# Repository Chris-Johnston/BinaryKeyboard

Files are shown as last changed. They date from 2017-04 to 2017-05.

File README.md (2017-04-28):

# BinaryKeyboard
A two-button backlit mechanical keyboard that types ASCII values, one bit at a time.

## Photos

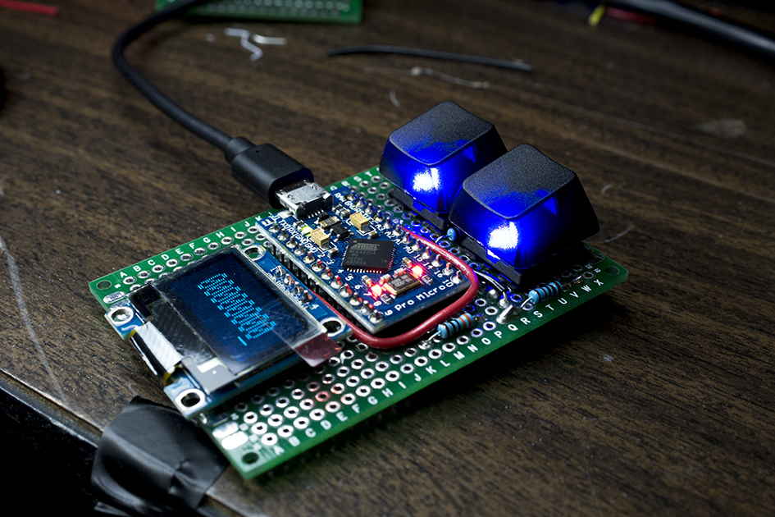
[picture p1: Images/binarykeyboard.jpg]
Photo of Binary Keyboard

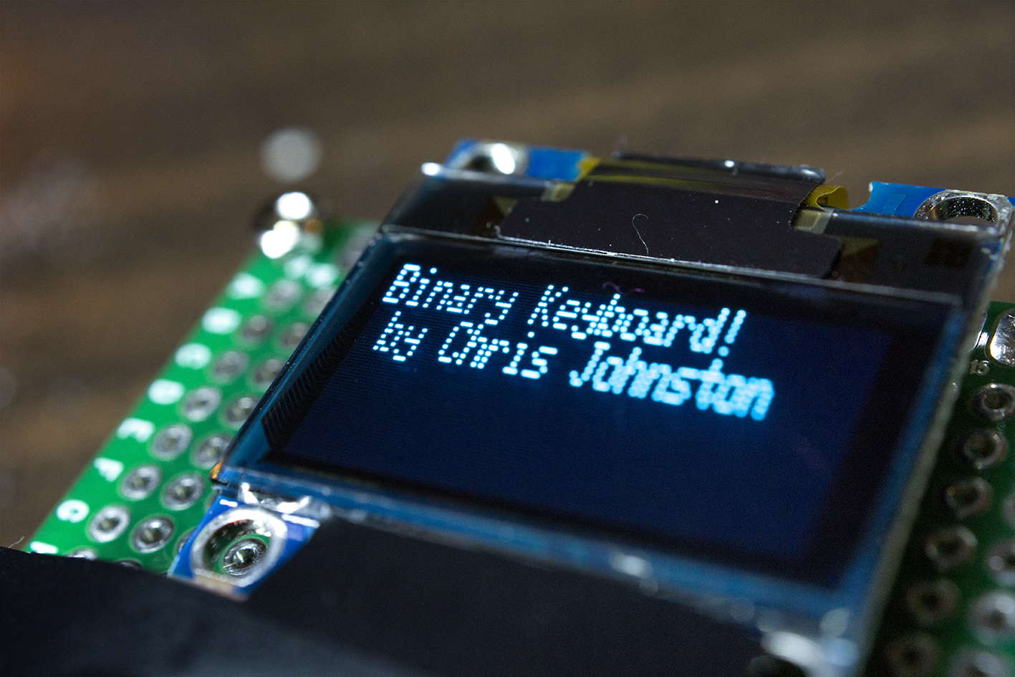
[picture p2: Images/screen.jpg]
Photo of Screen

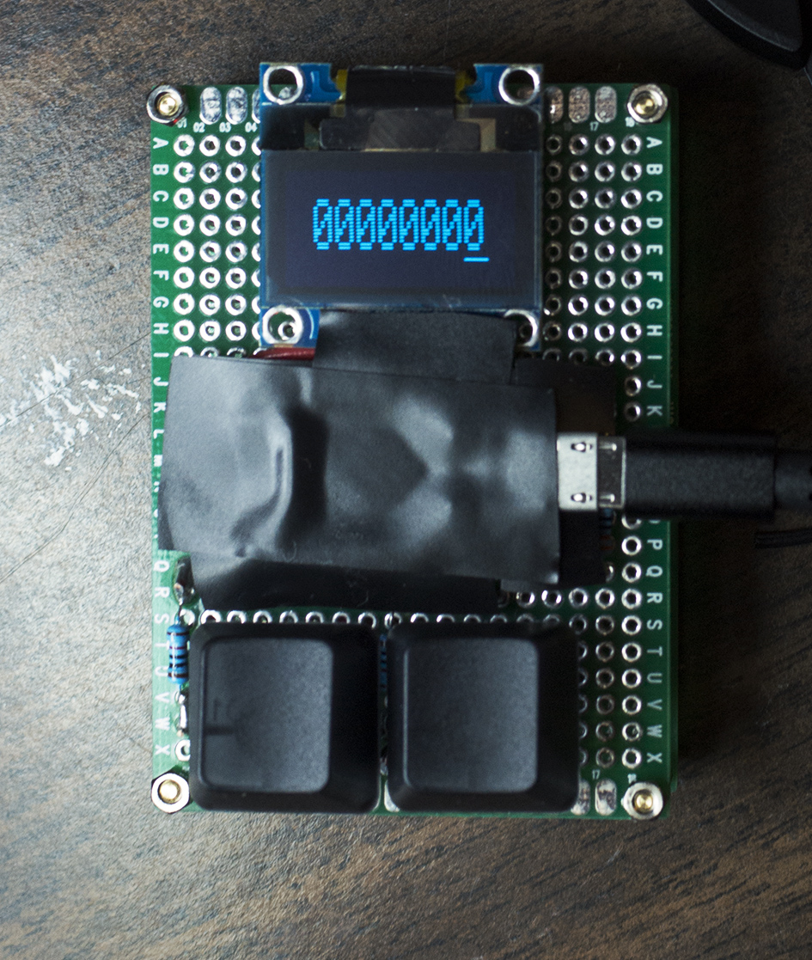
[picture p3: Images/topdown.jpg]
Top Down Photo


## GIFS

Mode switching and typing backspace

Typing the backspace character, followed by switching between modes.

Demonstrating left to right input

Demonstrating left to right input.

Showing off animations in updated alternate mode

New animations added to '1/0' mode. (Still working on a name for that).

Sample input using phone

Demonstrating compatibility with USB OTG.

Boot up sequence

Boot up sequence.

Normal use

Demonstrating right to left input.

Switching modes

Demonstrating switching between typing modes.

Fancy backlighting

Close-up of the blue led backlit keys.

# Technical Info

## Schematic
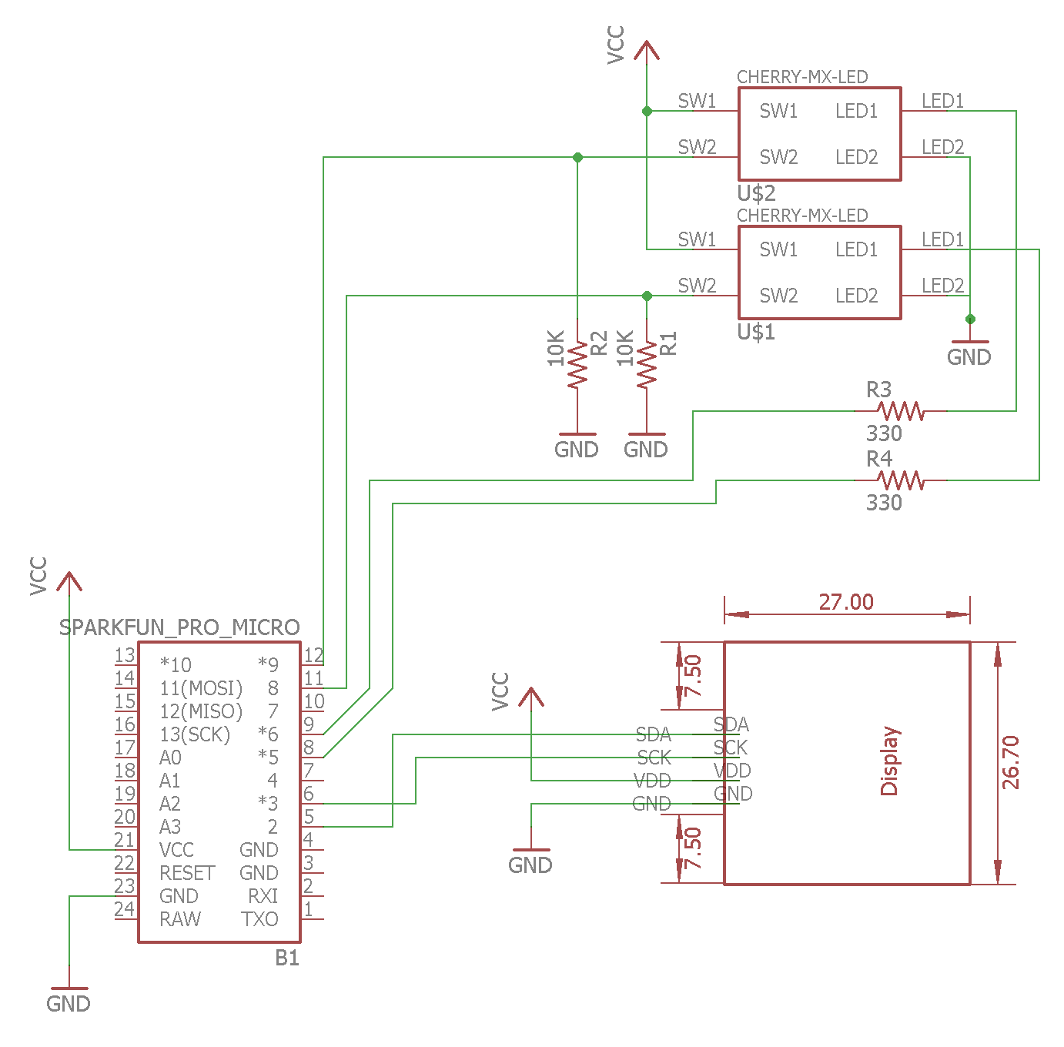
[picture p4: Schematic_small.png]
Image of Schematic


## Components
- Arduino Pro Micro (knockoff) [AliExpress - $3](https://www.aliexpress.com/store/product/Free-Shipping-New-Pro-Micro-for-arduino-ATmega32U4-5V-16MHz-Module-with-2-row-pin-header/318950_1348800135.html)
- Cherry MX Clear PCB Mount Mechanical Switches [MechanicalKeyboards.com - $10, w/ bulk pricing options](https://mechanicalkeyboards.com/shop/index.php?l=product_detail&p=594)
- SSD1306 OLED Display [AliExpress - $2.72](https://www.aliexpress.com/item/Wholesale-0-96-inch-4pin-White-OLED-Module-SSD1306-Drive-IC-128-64-I2C-IIC-Communication/32658908775.html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,searchweb201602_4_10152_10065_10151_10068_10130_10136_10137_10060_10138_10155_10062_10156_10154_10056_10055_10054_10059_10099_10103_10102_10096_10148_10147_10052_10053_10142_10107_10050_10051_10084_10083_10080_10082_10081_10178_10110_10111_10112_10113_10114_10181_10037_10078_10079_10077_10073_10070_10123_10124,searchweb201603_1,afswitch_1,ppcSwitch_3&btsid=055812c7-c728-4744-bd70-e33da76f8242&algo_expid=f8fb9ab1-cd07-4575-a544-a11a33f28421-2&algo_pvid=f8fb9ab1-cd07-4575-a544-a11a33f28421)
- Blue 2 * 3 * 4 mm LEDs [AliExpress - $2.29 / 100ct](https://www.aliexpress.com/item/EC-Buying-100pcs-2X3X4-LED-Blue-Transparent-DC-Rectangle-LED-Light-Emitting-Diode-2-3-4/32806132582.html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,searchweb201602_4_10152_10065_10151_10068_10130_10136_10137_10060_10138_10155_10062_10156_10154_10056_10055_10054_10059_10099_10103_10102_10096_10148_10147_10052_10053_10142_10107_10050_10051_10084_10083_10080_10082_10081_10178_10110_10111_10112_10113_10114_10181_10037_10078_10079_10077_10073_10070_10123_10124,searchweb201603_1,afswitch_1,ppcSwitch_3&btsid=54ec29ec-c549-4d5f-a95b-290ab57c28c5&algo_expid=802203e6-7262-45b3-bbf0-e52533f80bf5-0&algo_pvid=802203e6-7262-45b3-bbf0-e52533f80bf5)

## Arduino Library Requirements
These libraries are used to drive the SSD1306 OLED display.
- [Adafruit_GFX](https://github.com/adafruit/Adafruit-GFX-Library)
- [Adafruit_SSD1306](https://github.com/adafruit/Adafruit_SSD1306)

## Eagle Schematic Details
Because I could not locate a part to represent the SSD1306 OLED Display, I created my own. This can be found in the
`CSJ Library` file for Eagle. A word of warning, this was my first time using Eagle. The part works, but could be improved.

Uses [c0z3n/cherrymx-eagle](https://github.com/c0z3n/cherrymx-eagle/) library as well.

## Usage
Each byte can either be typed from most significant bit to least significant bit (left to right), or least significant bit to most significant bit (right to left). This is configured before compiling and uploading to the board.
After all 8 bits have been entered, it will type out the ASCII value equivalent of that binary value. The Pro Micro has USB HID support,
which means it acts just like any other keyboard.

If both keys are held down, the keyboard will switch to "1/0 mode" / "single button press mode" (I'm bad at names).
In this mode, each key will represent a '1' or a '0' just like on a traditional keyboard, no binary involved.

## Arduino Problems
Initially I was going to use a [DigiStump](http://digistump.com/products/1) board for this, but I found issues with not having enough memory to work with after importing libraries and not enough I/O. I'm using an Arduino Pro Micro knockoff. The reason that there is electrical tape covering it is because I found that shorting the contacts with a finger would cause it to stop working. I'm still not really sure why.

### Keyboard Class Limitations
This project relies on the Arduino Keyboard library to handle all USB HID support.
It works great for printing standard characters and most operations, however, a downside of using this means that
not all ASCII values are supported. [Most of the values below `0x20` are not actually supported.](https://github.com/arduino-libraries/Keyboard/blob/master/src/Keyboard.cpp#L88)

User [dtwilliamson](https://github.com/dtwilliamson) [added a feature](https://github.com/Chris-Johnston/BinaryKeyboard/pull/5) that repurposes these values as control commands.
[Here is a list of some control key commands](https://en.wikipedia.org/wiki/Control_key#Examples).

The functionality of Backspace, Tab, and Enter is still preserved by setting `HID_MODE` to `true`.

| Binary | `HID_MODE false` | `HID_MODE true` |
| --- | --- | --- |
| `00000001` | `L_CTRL + A` | `L_CTRL + A` |
| `00000010` | `L_CTRL + B` | `L_CTRL + B` |
| `00001000` | `L_CTRL + H` | `Backspace` |
| `00001001` | `L_CTRL + I` | `Tab` |
| `00001010` | `L_CTRL + J` | `Enter` |
| `00100000` | ` ` (whitespace) | ` ` (whitespace)|
| `00100001` | `!` | `!` |
| `01100001` | `a` | `a` |
| `01000001` | `A` | `A` |

Note that CTRL+H, CTRL+I, and CTRL+J function the same in a Unix command line as the keys do. Up to you which setting to use. `HID_MODE true` works just fine in Windows and the GNOME desktop environment.

# Contribution and Modifications
Please feel free to fork this project for your own purposes. If you build one, I would love to see it!

If you have suggestions/improvements/feedback/bug reports/etc., submitting a pull request or an issue through GitHub is the best way to contribute.

# Acknowledgments
Special thanks goes to everyone in the UWB Makerspace that helped make this possible.

Pixel art for screen animations by [@Omrii_](https://twitter.com/omrii_) https://github.com/OmriN7.

Please see the [Binary Keyboard contributors page](https://github.com/Chris-Johnston/BinaryKeyboard/graphs/contributors) for a list of contributors. Many thanks to each of you for your support!

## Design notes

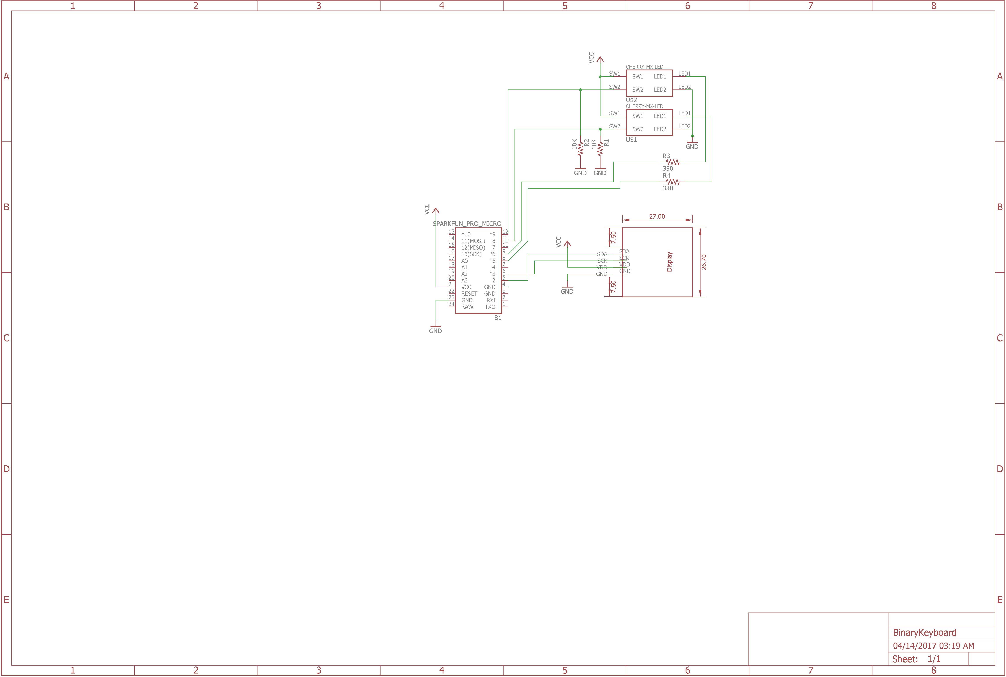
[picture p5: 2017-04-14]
Eagle/Schematic.png

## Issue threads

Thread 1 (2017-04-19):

Direction of typing

finalcircuit, 2017-04-19:
"Each bit is typed out from the least significant bit to the most significant bit (left to right)."

I may be misunderstanding (in which case just ignore) but shouldn't that be right to left?

Chris-Johnston, 2017-04-19:
Good catch. It was late when I wrote that. (Also I didn't know including "Fix #1" automatically closed issues!)

Also 8c26b709d78090d8bb76e2dc1e359d4b5347b95c now includes the option to specify right-to-left or left-to-right modes.

Closed 2017-04-19.

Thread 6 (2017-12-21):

Looking for Design Input

Chris-Johnston, 2017-12-21:
Now that I've been able to come back to this project, there are a few outstanding issues that need to be addressed. I've heard from a few that they'd be interested in seeing this project as a kit, but there are a few things I want to sort out beforehand.

I would appreciate any opinions on how I should move forward in continuing to design this. The goal is to make this approachable for newcomers who want to try it, and possibly get this ready to be manufactured and bundled with all the required parts as a DIY kit. It should be compatible with the current Arduino code, and down the line also compatible with the QMK firmware (see branch: 865c18a).

**Choice of Microcontroller**
I've been considering a few different options.
- ATTiny85. Small and cheap, but with a limited amount of memory and I/O, I don't think you can even load QMK firmware on it. Probably doesn't work for this purpose.
- Knockoff Pro Micro. These are also very cheap, at around ($3-5) a piece. They offer more than what is needed in terms of I/O. Their onboard LEDS are a bit too bright and get annoying, and there is no reset switch. If this is used with QMK, re-flashing would probably require a jumper (which I could add to the PCB).
- Teensy 2.0. These are common among custom DIY keyboards, so there's plenty of support. You could re-use these as long as you have female headers. They are also smaller than the pro micro. The price at around $20 per unit is the biggest factor here, I think that hurts the "novelty" nature of the idea.
- Get some ATMega32u4's as surface mount components and put it right on the board. This would be great, but sounds tricky. I want something that's going to be reliable and easy to build.

**Display / No Display / RGB LEDs**
While those SSD1306 displays are cool, there are other options that can be used.
- Keep the OLED display from the original keyboard. This allows for animations and other stuff. Modifying the QMK firmware to support it appears possible (it's been a while since I've tried last), but might be tricky. Also, finding a library that has a license I can use. Designing a board and case may be tricky.
- Use 8 surface mount LEDs, or a package containing 8 surface mount LEDs, like this:
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 This would work, but wouldn't be as fun.
- Use 8 RGB NeoPixel LEDs. This works with QMK and could also support other patterns, should this end up repurposed as a macro pad. PCB space is limited, so positioning 8 of these LEDs in such a small space may be tricky. They are also very bright to stare at directly at full brightness.

**Board Layout**
I've been experimenting with different layouts and board sizes.
- The smallest, most compact design has the keys on the top, microcontroller (pro micro) _underneath_ around the keys, and the display hanging off of the top. I've assembled a version of this and it's ok when handheld, but is a bit too light to have on a desk, it gets pulled away from the cable. The downside to this is a somewhat awkward shape, and it's tricky to put together. Getting to the contacts under the microcontroller is a pain. The small board size means that manufacturing cost (PCBWay for cheaper, larger qty, OshPark for faster but more expensive) is reduced.
  - 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
- A larger, roomier design that allows for easier modification (and will probably be easier to design a case for). The biggest downside to this is the cost, but should be fine as long as it is relatively small. This version has the screen (attached via female headers) hanging over the microcontroller (a teensy in this case), but it can be moved around.
  - 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

**Other things left to do**
- [ ] Look into designing the board as a single side, so that it can be etched DIY.
- [ ] I should probably redo the board in KiCAD, due to licensing reasons.
   - [ ] I need to find or design my own cherry MX profile, the one I've used has the LEDs in the wrong position and only works if they are bent into place.
   - [ ] I need to make a better SSD1306 part than what I have right now
- [ ] I need to get a working modification of the QMK firmware that supports the SSD 1306 display.
   - [ ] I need to find a library that I can use for the SSD 1306 display w/ QMK.
- [ ] Finalize parts list.

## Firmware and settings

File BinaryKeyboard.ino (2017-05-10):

/*
	Binary Keyboard
	For full source and contributors, please visit: https://github.com/Chris-Johnston/BinaryKeyboard
*/

// Included Libraries for Arduino Micro
#include <Keyboard.h>
#include <Wire.h>
#include <SPI.h>

/*
	Prerequisite Libraries
	These must be in your libraries directory before building!
	See https://www.arduino.cc/en/Guide/Libraries for more details.
*/

// Adafruit GFX - https://github.com/adafruit/Adafruit-GFX-Library
// Provides methods used for drawing.
#include <Adafruit_GFX.h>


// Adafruit SSD1306 - https://github.com/adafruit/Adafruit_SSD1306
// Enables support for the SSD1306 OLED display.
#include <Adafruit_SSD1306.h>

// Pixel Art Frame Definition File
#include "PixelArt.h"

/*
	Software Configuration Definitions
	Adjust these to your preference before compiling and uploading.
*/

// flag for reading/entering right to left or left to right
// true = right to left (least significant bit to most)
// false = left to right (most significant bit to least)
#define USE_RIGHT_TO_LEFT false

// flag for outputting chars in HID keyboard mode or pure ctrl char mode (pure ASCII)
// true = HID keyboard - outputs keyboard codes for Backspace (8), Tab (9) and Enter (10), otherwise ctrl chars as below
// false = Ctrl char ASCII - outputs ctrl char corresponding to byte value entered (BS == Ctrl-H, Tab == Ctrl-I, Enter == Ctrl-J, etc.)
#define HID_MODE true

// Output characters for "Single button press mode"
//todo allow picking which side is which character, currently is kinda flip flopped
#define CHAR_ZERO '0' // right
#define CHAR_ONE '1' // left

// time in ms to hold both buttons to switch modes
#define DELAY_SWITCH_MODES 2000
// time in ms to show the last printed character on screen
#define DELAY_SHOW_LAST_PRINTED 2000
// toggle to disable changing modes
#define CAN_SWITCH_MODES true

// LED PWM value decay rate
#define LED_DECAY_RATE 10

// which mode to start up in. False = Binary Mode, True = Single button press mode
#define MODE_ON_START false

/*
	Configuration Definitions
	Adjust these to match your circuit and hardware before compiling and uploading.
*/

// Button Pins - Connected as input
#define BUTTON_ZERO 8
#define BUTTON_ONE 9

// Led Pins - Connected as PWM output
#define LED_ZERO 5
#define LED_ONE 6

// time in ms for button debouncing
// cherry reports <= 5 ms debounce : http://cherryamericas.com/product/mx-series-2/#84b4bc7a7a0396678
#define DELAY_DEBOUNCE 5


// Rotation of the SSD_1306 OLED Display
// In testing, 2 rotated the screen so that the up direction faced away from the pins.
// 0 rotated the screen so that the up direction faced toward the pins.
// YMMV

#define SCREEN_ROTATION 2

/* Other Definitions */

// These are the indices into the _asciimap array defined in Arduino Keyboard.cpp
#define HID_BS 0x08
#define HID_TAB 0x09
#define HID_ENTER 0x0A

// Strings to display when in HID mode
#define HID_BS_STRING "BS"
#define HID_TAB_STRING "Tab"
#define HID_ENTER_STRING "Enter"

// set up display
#define OLED_RESET 4
Adafruit_SSD1306 display(OLED_RESET);

// resolution of the SSD_1306 display
#define X_RESOLUTION 128
#define Y_RESOLUTION 32

// various timers for debouncing, animations, mode switching

// indicates the time of the last button press for each button
unsigned long debounceTimerZero = 0;
unsigned long debounceTimerOne = 0;

// the timer used to track how long both buttons have been pressed down
unsigned long switchModeTimerStartPress = 0;

// time when last character was printed out
unsigned long lastPrintTime = 0;

// the timer used to track when the last time modes were switched
unsigned long switchTime = 0;

// used for one/zero mode animation timing
unsigned long timerOne = 0, timerZero = 0;

// flag for the current mode
bool mode = MODE_ON_START; // false = binary mode, true = single button press mode

// value of the last printed character
char lastPrinted = ' ';

// keystroke value being entered
byte keyStroke = 0;
// the index of the byte being entered
int index = 0;

// values for the state of each of the buttons
bool buttonStateZero, buttonStateOne;
// PWM values for each led
int ledZero, ledOne;


void setup() {

	//todo deal with ASCII values > 128. it actually looks like Keyboard.h does not support these.
	//not sure if I can get around it or if I should restrict to only using normal ASCII table

	if (USE_RIGHT_TO_LEFT)
	{
		index = 0;
	}
	else
	{
		index = 7;
	}

	//Serial.begin(9600);
	Keyboard.begin();

	// leds
	pinMode(LED_ZERO, OUTPUT);
	pinMode(LED_ONE, OUTPUT);

	// buttons
	pinMode(BUTTON_ZERO, INPUT);
	pinMode(BUTTON_ONE, INPUT);

	// display
	display.begin(SSD1306_SWITCHCAPVCC, 0x3C);
	// set screen rotation
	display.setRotation(SCREEN_ROTATION);

	// do some fancy screen stuff on boot
	display.clearDisplay();
	display.setCursor(0, 0);
	display.setTextColor(WHITE);
	display.print("Binary Keyboard!\ngithub.com/\n     Chris-Johnston");
	display.display();
	delay(1000);
	// wipes the screen away with an effect
	display.setCursor(0, 0);
	int width = 15;
	for (int i = 0; i < X_RESOLUTION / 6 + width + Y_RESOLUTION / 8; i++)
	{
		analogWrite(LED_ZERO, millis() / 2 % 255);
		analogWrite(LED_ONE, millis() / 2 % 255);

		// iterate horizontally
		for (int j = 0; j < Y_RESOLUTION / 8; j++)
		{
			//iterate vertically
			char c = ((i + j) % 2) ? '1' : '0';
			if (i == 2 && j == 2)
			{
				c = '2'; // wonder if anyone will notice? EDIT: Yes, people did. LOL
				/*
				* Bender:	Whoa, what an awful dream. Ones and zeroes everywhere. And I thought I saw a two.
				* Fry:		It was just a dream Bender. There's no such thing as two.
				*/
			}
			display.drawChar(i * 6, j * 8, c, WHITE, BLACK, 1);
			display.drawChar((i - width) * 6, j * 8, ' ', WHITE, BLACK, 1);
		}
		delay(10);
		display.display();
	}

	analogWrite(LED_ZERO, 0);
	analogWrite(LED_ONE, 0);
}

/*
	Method called whenever a key is pressed down in binary mode
	val is assumed to be either a 1 or a 0
*/
void keypress(int val)
{
	if (USE_RIGHT_TO_LEFT)
	{
		// clear the keystroke only when starting to type once again
		if (index == 0) { keyStroke = 0; }

		keyStroke += val << index;
		// index increments from 0 -> 7 when RTL
		index++;

		if (index > 7)
		{
			sendVal((char)keyStroke);
			index = 0;
		}
	}
	else
	{
		// clear the keystroke only when starting to type once again
		if (index == 7) { keyStroke = 0; }

		keyStroke += (val << index);
		// index decrements from 0->7 when LTR
		index--;

		if (index < 0)
		{
			sendVal((char)keyStroke);
			index = 7;
		}
	}
}

/*
	Handles writing a value in binary mode
*/
void sendVal(char val)
{
    if (val >= 32 || (HID_MODE && (val == HID_BS || val == HID_TAB || val == HID_ENTER))) {
        Keyboard.write(val);
    } else {
		// for ASCII < 0x20, use control characters in lowercase
        Keyboard.press(KEY_LEFT_CTRL);
        Keyboard.press(val + 96);
        Keyboard.releaseAll();
    }
	// update timers and last printed value to be used for drawing output
    lastPrintTime = millis();
    lastPrinted = val;
}

/*
	Handles the displaying of control characters
*/
void dispCtrlChar(char val)
{
    display.print('^');
    display.print((char)(val + 64)); // Use uppercase representation (e.g. ^A instead of ^a)
}

void loop() {
	bool previousZero = buttonStateZero;
	bool previousOne = buttonStateOne;

	buttonStateOne = digitalRead(BUTTON_ONE);
	buttonStateZero = digitalRead(BUTTON_ZERO);

	// write LED values
	analogWrite(LED_ZERO, ledZero);
	analogWrite(LED_ONE, ledOne);

	ledZero = max(0, ledZero - LED_DECAY_RATE);
	ledOne = max(0, ledOne - LED_DECAY_RATE);

	display.clearDisplay();

	// display the last printed character in binary keyboard mode for a given amount of time
	if (!mode)
	{
		if ((millis() - lastPrintTime) < DELAY_SHOW_LAST_PRINTED)
		{
			display.setCursor(0, 0);
			display.setTextSize(1);
			display.print("Last: ");
			// handle printing of control characters or their equivalents
            if (lastPrinted > 0 && lastPrinted < 32)
            {
                if (HID_MODE)
                {
                    switch (lastPrinted)
                    {
                        case HID_BS:
                            display.print(HID_BS_STRING);
                            break;
                        case HID_TAB:
                            display.print(HID_TAB_STRING);
                            break;
                        case HID_ENTER:
                            display.print(HID_ENTER_STRING);
                            break;
                        default:
                            dispCtrlChar(lastPrinted);
                            break;
                    }
                }
                else
                {
                    dispCtrlChar(lastPrinted);
                }
            }
            else
            {
                display.print(lastPrinted);
            }
        }

		// print out all 8 bits in (roughly) the center of the screen
		display.setTextSize(2);
		display.setTextColor(WHITE, BLACK);
		display.setCursor(16, 8);
		for (int i = 7; i >= 0; i--)
		{
			display.print(bitRead(keyStroke, i));
		}
		display.drawLine((8 - index - 1) * 12 + 16, 24, (8 - index) * 12 + 16, 24, WHITE);
	}

	// do backlighting stuff
	if (buttonStateOne)
	{
		ledOne = 255;
	}
	if (buttonStateZero)
	{
		ledZero = 255;
	}

	// handle switching between modes
	if (buttonStateZero && buttonStateOne && CAN_SWITCH_MODES)
	{
		if (switchModeTimerStartPress == 0)
		{
			// track when both buttons were first pressed
			switchModeTimerStartPress = millis();
		}
		// when both buttons were pressed DELAY_SWITCH_MODES ms ago, switch the mode
		// probably don't have to test that previousOne and previousZero are true
		else if (((millis() - switchModeTimerStartPress) > DELAY_SWITCH_MODES) && previousOne && previousZero)
		{
			switchModeTimerStartPress = millis();
			mode = !mode;
			switchTime = millis();
			lastPrinted = '0';
			Keyboard.releaseAll();
		}

		// draw a 'progress bar' indicating when this will switch over
		int width = map(millis() - switchModeTimerStartPress, 0, DELAY_SWITCH_MODES, 0, X_RESOLUTION);
		display.drawRect(0, 30, width, 2, WHITE);
	}
	else
	{
		// reset the timer when both buttons are not being pressed
		switchModeTimerStartPress = 0;
	}

	// if single button press mode
	if (mode)
	{
		// if one is debounced
		if ((millis() - debounceTimerOne) > DELAY_DEBOUNCE)
		{
			// check if it has been pressed
			if (buttonStateOne && !previousOne)
			{
				// the press function will press this button down and it will not be released
				// unless explicitly told to
				Keyboard.press(CHAR_ONE);
				debounceTimerOne = millis();
				//timerOne = millis();
			}
		}
		if(!buttonStateOne)
		{
			// time on release
			timerOne = millis();
			Keyboard.release(CHAR_ONE);
		}

		// do animation for button one (left)
		if (!buttonStateOne)
		{
			display.drawChar(TEXT_X_1, TEXT_Y_0, CHAR_ONE, WHITE, BLACK, 2);
			display.drawBitmap(KEY_X_0, KEY_Y_0, FRAME_0, ART_WIDTH, ART_HEIGHT, WHITE);
		}
		else
		{
			int v = (millis() - timerOne);// / FRAME_DELAY_MS;
			if (v <= FRAME_DELAY_MS * 1)
			{
				display.drawChar(TEXT_X_1, TEXT_Y_1, CHAR_ONE, WHITE, BLACK, 2);
				display.drawBitmap(KEY_X_0, KEY_Y_0, FRAME_1, ART_WIDTH, ART_HEIGHT, WHITE);
			}
			else if (v <= FRAME_DELAY_MS * 2)
			{
				display.drawChar(TEXT_X_1, TEXT_Y_2, CHAR_ONE, WHITE, BLACK, 2);
				display.drawBitmap(KEY_X_0, KEY_Y_0, FRAME_2, ART_WIDTH, ART_HEIGHT, WHITE);
			}
			else if (v <= FRAME_DELAY_MS * 3)
			{
				display.drawChar(TEXT_X_1, TEXT_Y_3, CHAR_ONE, WHITE, BLACK, 2);
				display.drawBitmap(KEY_X_0, KEY_Y_0, FRAME_3, ART_WIDTH, ART_HEIGHT, WHITE);
			}
			else
			{
				display.drawChar(TEXT_X_1, TEXT_Y_4, CHAR_ONE, WHITE, BLACK, 2);
				display.drawBitmap(KEY_X_0, KEY_Y_0, FRAME_4, ART_WIDTH, ART_HEIGHT, WHITE);
			}
		}

		// handle stuff for button zero

		// if zero is debounced
		if ((millis() - debounceTimerZero) > DELAY_DEBOUNCE)
		{
			// check if it has been pressed
			if (buttonStateZero && !previousZero)
			{
				Keyboard.press(CHAR_ZERO);
				debounceTimerZero = millis();
			}
		}
		if (!buttonStateZero)
		{
			// time on release
			timerZero = millis();
			Keyboard.release(CHAR_ZERO);
		}

		// do animation for button zero (right)
		if (!buttonStateZero)
		{
			display.drawChar(TEXT_X_2, TEXT_Y_0, CHAR_ZERO, WHITE, BLACK, 2);
			display.drawBitmap(KEY_X_1, KEY_Y_0, FRAME_0, ART_WIDTH, ART_HEIGHT, WHITE);
		}
		else
		{
			int v = (millis() - timerZero);// / FRAME_DELAY_MS;
			if (v <= FRAME_DELAY_MS * 1)
			{
				display.drawChar(TEXT_X_2, TEXT_Y_1, CHAR_ZERO, WHITE, BLACK, 2);
				display.drawBitmap(KEY_X_1, KEY_Y_1, FRAME_1, ART_WIDTH, ART_HEIGHT, WHITE);
			}
			else if (v <= FRAME_DELAY_MS * 2)
			{
				display.drawChar(TEXT_X_2, TEXT_Y_2, CHAR_ZERO, WHITE, BLACK, 2);
				display.drawBitmap(KEY_X_1, KEY_Y_1, FRAME_2, ART_WIDTH, ART_HEIGHT, WHITE);
			}
			else if (v <= FRAME_DELAY_MS * 3)
			{
				display.drawChar(TEXT_X_2, TEXT_Y_3, CHAR_ZERO, WHITE, BLACK, 2);
				display.drawBitmap(KEY_X_1, KEY_Y_1, FRAME_3, ART_WIDTH, ART_HEIGHT, WHITE);
			}
			else
			{
				display.drawChar(TEXT_X_2, TEXT_Y_4, CHAR_ZERO, WHITE, BLACK, 2);
				display.drawBitmap(KEY_X_1, KEY_Y_1, FRAME_4, ART_WIDTH, ART_HEIGHT, WHITE);
			}
		}
	}
	else // in normal binary keyboard mode
	{
		// debouncing for each button
		if ((millis() - debounceTimerZero) > DELAY_DEBOUNCE)
		{
			// zero pressed, and one is not pressed (otherwise this would cause issues with holding down both)
			if (buttonStateZero && !buttonStateOne && !previousZero)
			{
				keypress(0);
				debounceTimerZero = millis();
			}
		}

		if ((millis() - debounceTimerOne) > DELAY_DEBOUNCE)
		{
			// one pressed, and zero is not pressed
			if (!buttonStateZero && buttonStateOne && !previousOne)
			{
				keypress(1);
				debounceTimerOne = millis();
			}
		}
	}

	// actually update the screen with these graphics
	display.display();
}

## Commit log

2017-04-14 Added schematic, screenshots, major updates to code
    [BinaryKeyboard.sch]
2017-04-22 Moved Eagle specific files into Eagle folder
    Also removed tracking of Eagle files as overall project
    [BinaryKeyboard.sch]
2017-04-27 correct logic in display of ctrl chars
    [BinaryKeyboard.ino]
2017-04-28 Added comments. Defined constants. Separated debounce timers. Added flag to disable switching.
    I am more than guilty of doing too much in a single commit.
    Added a ton of comments so that newbies might get it.
    Changed variables that were used as constant to just be #define 'd
    instead. No more magic #s?
    For some reason I was using a single debounce timer for both buttons.
    Fixed. In addition added debounce to single button press mode.
    Added CAN_SWITCH_MODES for those who just want one mode or the other.
    [BinaryKeyboard.ino]
2017-04-28 revised comments and readme regarding control character letter case
2017-05-10 Fixed held buttons on switching modes
    previously, one button may have been held down when modes are switched
    [BinaryKeyboard.ino]
